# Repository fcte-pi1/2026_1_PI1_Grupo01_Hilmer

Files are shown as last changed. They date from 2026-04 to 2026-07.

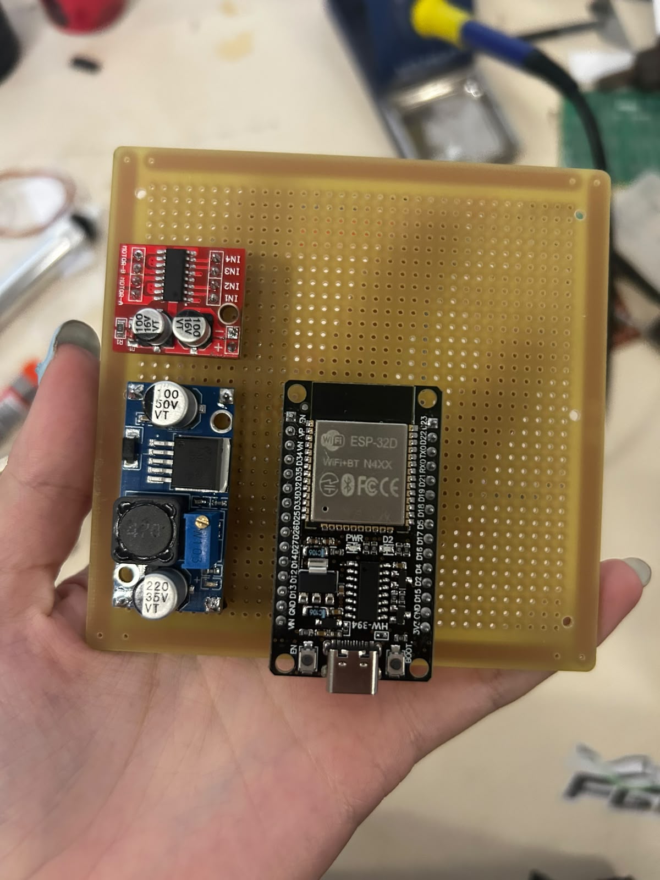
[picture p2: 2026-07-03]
hw/img/4.jpeg

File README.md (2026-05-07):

# Template PI1

Esse é o _template_ de repositório para ser utilizado pelos grupos de PI1 para organizar seu projeto. O _template_ é dividido em pastas, onde cada parte do projeto deve ser armazenada. Os arquivos a serem armazenados incluem documentação, código-fonte, arquivos de CAD, esquemáticos, arquivos de simulação de circuitos, e dados.

A organização e a correta utilização do repositório do projeto serão considerados na avaliação do grupo. Dessa forma, recomenda-se que *todos os membros* do grupo leiam as instruções deste repositório, aprendam a a utilizar o git (caso ainda não saibam) e também que o grupo combine uma estratégia de como irão utilizar o repositório em conjunto. Dessa forma não deixem de utilizar todas as ferramentas que o GitHub oferece, incluindo branchs, PRs, revisões, issues, calendários, dentre outros.

Lembrem sempre de evitar enviar arquivos muito grandes (>5MB). No caso de vídeos e outros arquivos pesados que são necessários, armazenar o arquivo em outra plataforma e colocar aqui apenas o _link_.

> [!IMPORTANT]
> A estrutura de pastas do projeto não reflete a divisão de equipes. Os membros podem e devem trabalhar nas diferentes pastas a depender da necessidade do projeto.

## Utilização

1. Crie o repositório do projeto utilizando a nomenclatura padrão no formato: `<ano>.<semestre>_PI1_Grupo<n>_<professor>`. Como um exemplo, um nome formado corretamente seria `2026.1_PI1_Grupo1_Diogo`. 

2. Crie uma equipe do projeto com a mesma nomenclatura do repositório porém com o sufixo `_Equipe`, como `2026.1_PI1_Grupo1_Diogo_Equipe`, e solicite, caso necessário, que a equipe tenha permissão de escrita no repositório do projeto.

## Configuração de ambiente

O script [scripts/setup_dev_env.sh](/home/lucasmf/projects/PI1/2026_1_PI1_Grupo01_Hilmer/scripts/setup_dev_env.sh:1) prepara o ambiente de desenvolvimento levando em conta o estado atual do projeto:

- frontend em `React + Vite`
- backend em `Node.js`
- banco de dados ainda pendente de definição
- comunicação com sensores por `HTTP`, com hardware ainda pendente de definição
- auditoria da estrutura atual do repositório ao final da execução

Para instalar dependências e validar o ambiente:

```bash
bash scripts/setup_dev_env.sh install
```

Esse modo instala apenas as dependências do projeto, com base nos `package.json` de `src/backend` e `src/frontend`.

Para instalar pacotes de sistema necessários ao ambiente:

```bash
bash scripts/setup_dev_env.sh install-system
```

Para apenas checar o ambiente atual, sem instalar nada:

```bash
bash scripts/setup_dev_env.sh check
```

Para iniciar frontend e backend automaticamente:

```bash
bash scripts/start_dev.sh
```

Esse script sobe os dois serviços juntos e encerra ambos ao usar `Ctrl+C`.

O script tenta instalar:

- dependências de `src/backend` quando existir `package.json`
- dependências de `src/frontend` quando existir `package.json`

No modo `install-system`, o script tenta instalar:

- `git`
- `curl`
- utilitários básicos de compilação do sistema

Observações:

- O modo `install` não usa `sudo` nem instala pacotes do sistema.
- Em Linux/macOS, o modo `install-system` pode pedir `sudo`.
- O script usa `npm ci` quando existir `package-lock.json`; caso contrário, usa `npm install`.
- O script copia `.env.example` para `.env` em `src/backend` e `src/frontend` quando esses arquivos existirem.
- O banco de dados e o hardware de comunicação com sensores ainda precisam ser definidos pelo time.

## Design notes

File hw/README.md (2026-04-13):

# _Hardware_

Esta pasta deverá armazenar arquivos referentes a:

- Simulações de circuitos eletrônicos (alimentação, sensores, atuadores etc.): [Qucs](https://qucs.sourceforge.net/), [QSPICE](https://www.qorvo.com/design-hub/design-tools/interactive/qspice), [Fritzing](https://fritzing.org/), dentre outros.
- Esquemáticos de circuitos: [KiCad](https://www.kicad.org/), Qucs, QSPICE.
- Diagramas de bloco: [Canva](https://www.canva.com/pt_br/), [TikZ](https://tikz.net/).
- _Datasheets_ de componentes eletrônicos, microcontroladores, _shields_ Arduino, motores etc.
- Testes tabelados de circuitos: arquivos CSV, Excel.
- Imagens PNG e JPEG de resultados práticos: fotos de testes reais, gráficos de resultados etc.
- Outros arquivos referentes ao _hardware_ do projeto.

> [!WARNING]
> **Não acrescente código-fonte a esta pasta.** O código desenvolvido para microcontroladores e SOCs ([Arduino](https://www.arduino.cc/), [ESP32](https://www.espressif.com/), [Raspberry Pi](https://www.raspberrypi.com/)) deverá ser armazenado na pasta [src/firmware](https://github.com/fcte-pi1/template/tree/main/src/firmware) deste repositório.

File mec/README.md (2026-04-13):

# _Mecânica e Estruturas_

Esta pasta deverá ser utilizada para armazenar arquivos relativos ao projeto estrutural, mecanismos, materiais, estudos aerodinâmicos, equações dinâmicas, construção e manufatura, impressão 3D, e correlatos.

Os arquivos a serem incluídos, são, dentre outros:
- Arquivos CAD de peças e montagens (FCStd, STEP, etc). 
- Desenhos técnicos (pdf, etc).
- Arquivos de impressão 3D (STL, etc).
- Imagens rasterizadas e vetorizadas (eps, pdf, svg, etc).
- Documentos e estudos realizados para o projeto (markdown, LaTeX, etc).

Durante o projeto, os grupos são encorajados a realizarem estudos para o projeto de estruturas, mecanismos, aerodinamica, dentre outros, e muitos desses estudos não caberão no relatório a ser entregue. Esses estudos podem ser colocados também nessa pasta, preferencialmente utilizando markdown (.md) para facilitar a leitura em ambiente web. Lembre-se que você pode utilizar equações em formato LaTeX no markdown e não deixe de utilizar links para o material de referencia que utilizaram. Estudos bem realizados contarão de maneira positiva na avaliação das equipes, porém lembre-se que não é permitida a utilização de IA, e que esse material deve ser principalmente útil à equipe.

> [!WARNING]
> Não acrecente arquivos da parte de hardware eletrônico aqui, como arquivos de KiCAD. Estes devem ser salvos na pasta [hw](https://github.com/fcte-pi1/template/tree/main/hw) deste repositório.

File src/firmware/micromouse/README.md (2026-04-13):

# _Firmware_
Esta pasta deverá armazenar arquivos referentes a:

- Código-fonte para microcontroladores e SOCs: [Arduino](https://www.arduino.cc/), [ESP32](https://www.espressif.com/), [Raspberry Pi](https://www.raspberrypi.com/), dentre outros.
- Projetos de organização destes códigos, caso utilize IDEs: [Arduino IDE](https://www.arduino.cc/en/software/), [Visual Studio](https://visualstudio.microsoft.com/pt-br/downloads/) etc.
- Arquivos de configuração: ```CMakeLists.txt``` se for usar [CMake](https://cmake.org/download/), ```Makefile``` se for usar [make](https://www.cs.colby.edu/maxwell/courses/tutorials/maketutor/) etc.

Evite incluir:
- Artefatos de compilação: os arquivos de saída compilados (binários, arquivos objeto, .hex, .elf) devem ser gerados pelo processo de compilação e não incluídos no repositório.
- Arquivos temporários/específicos do sistema operacional: Arquivos como .DS_Store (macOS) ou arquivos de configuração do editor (a menos que esteja usando uma configuração compartilhada como .editorconfig).
- Configurações pessoais: Arquivos de configuração locais específicos da máquina do desenvolvedor.

> [!WARNING]
> **Não acrescente arquivos referentes a _hardware_ nesta pasta.** Eles deverão ser armazenados na pasta [hw](https://github.com/fcte-pi1/template/tree/main/hw) deste repositório.

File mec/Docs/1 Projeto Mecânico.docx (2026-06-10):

1 Projeto Mecânico

  1.1 Análise Dinâmica

A primeira Lei de Newton define que a força resultante de um corpo é fruto do produto entre a massa e a aceleração. Portanto, é necessário analisar como a massa age no sistema de um micromouse e qual é o efeito da sua distribuição na estrutura, além de entender o funcionamento das forças que geram aceleração no rato. As análises realizadas aqui levam em conta a simplificação de que o centro de massa e o centro de gravidade (CG), local de atuação da força peso, coincidem quando o corpo é pequeno em relação à terra.

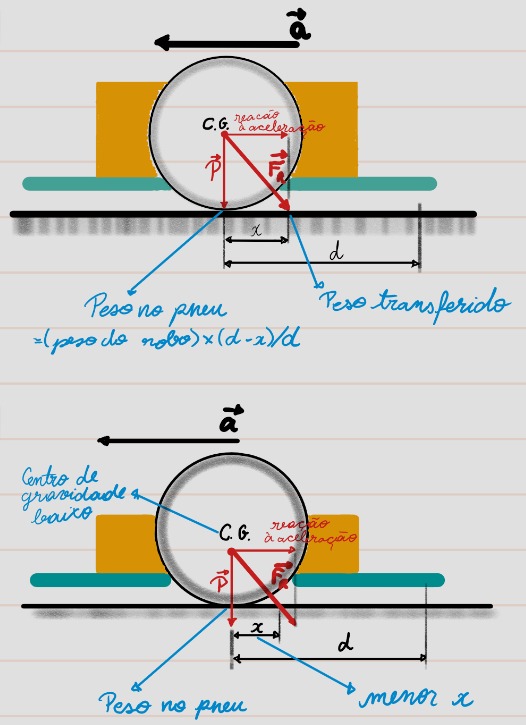
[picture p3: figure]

A força peso, e, portanto, a massa, possui três comportamentos importantes: no rato parado, no rato em aceleração ou desaceleração e no rato sob efeito de uma força centrípeta. Com o rato parado, todo o peso é transferido para as rodas, que são os pontos de contato do micromouse com o solo. Assim que o micromouse começa a acelerar, esse peso é deslocado por causa da reação à aceleração, como mostra a figura (nº da figura). Dessa forma, o peso para de manter a aderência do micromouse, pois ele se move para um ponto que não está em contato com o chão. O mesmo efeito ocorre na desaceleração, mas com sentido oposto.

Quando o CG é rebaixado, o vetor da força peso continua para além do solo, fazendo com que o deslocamento do peso diminua. Quanto mais baixo o CG, menor será o deslocamento do peso durante a aceleração, garantindo que ainda haja peso nas rodas e, portanto, que haja aderência. A fim de que o CG se mantenha próximo do solo e centralizado em relação aos pneus, os componentes mais pesados, como a bateria, são colocados no andar inferior do micromouse, perto das rodas, e de forma simétrica.

O momento em que o rato está sujeito à força centrípeta é quando ele realiza uma curva. Assim como no caso da aceleração, a força centrípeta gera uma reação que transfere o peso do centro do rato para a roda externa à curva. Essa transferência de peso para a extremidade gera um torque com centro de curvatura no ponto de contato entre a roda e o chão e raio do tamanho da distância do centro de gravidade ao solo. Dessa forma, quanto mais estreito o micromouse, mais o peso é transferido para a extremidade e quanto maior o CG, mais propenso o rato é a capotar na curva, pois exige menos esforço para gerar o torque. O diagrama de corpo livre da figura (nº da figura) demonstra que, para diminuir esse efeito, é preciso que o rato seja o mais largo possível e reitera a necessidade de um CG baixo.

  1.2 Dimensionamento

O estudo do comportamento das forças atuantes na movimentação do micromouse revelou duas coisas importantes para o dimensionamento: que as peças devem ser dispostas de modo a concentrar o peso na parte inferior e que o micromouse deve ser o mais largo possível. Contudo, ainda é preciso definir quais dimensões exatas são viáveis para o projeto.

A principal restrição de tamanho são as dimensões físicas do labirinto, pois o rato deve ser capaz, acima de tudo, de ser colocado dentro dele. Dessa forma, conclui-se que, no máximo, o micromouse pode ter 18cm de largura por 18 cm de comprimento. Apesar de ser um requisito importante, apenas caber no labirinto não garante que o micromouse será capaz de navegar por ele. Para isso, é preciso considerar a área que ele ocupa ao realizar as curvas, onde o espaço disponível para o rato é mínimo.

Existem diferentes curvaturas possíveis dentro do labirinto, contudo, mas mais críticas são as de 45º e de 90º, representadas na figura (nº da figura) são elas que delimitam, respectivamente, a maior largura e maior comprimento que o micromouse pode ter. Nas curvas de 45º o rato percorre um corredor decorrente de curvas consecutivas para lados alternados, o qual é limitado pelas quinas das paredes das células e possui uma largura de aproximadamente 127,3 mm. Sendo assim, a largura máxima que o micromouse pode ter é de 127 mm. Já nas curvas de 90º, o rato descreve uma trajetória com raio de 90mm, e a distância máxima entre o centro de rotação do rato e a sua extremidade é a que permite que esse trajeto seja realizado sem encostar nas paredes. Essa distância é de aproximadamente 101,1 mm, limitando o comprimento do micromouse a 202,2mm.

Para que o rato consiga realizar todo o caminho até a resposta sem obstáculos, optamos por deixar uma sobra de aproximadamente 60mm no comprimento e 30mm na largura, considerando que é importante o rato ser o mais largo possível. Assim, o rato possui 14cm de comprimento por 10cm de largura, sendo que o centro de rotação está situado no seu centro geométrico.

  1.3 Locomoção

A locomoção do micromouse depende, principalmente, do posicionamento e geometria das rodas e da disposição dos motores. Essas características são definidas por três propriedades: estabilidade, manobragem e controle (livrinho que eu vou mandar).

No âmbito da estabilidade, apenas duas rodas são necessárias, contudo, essa configuração requer rodas grandes demais para um micromouse. Sendo assim, o mínimo viável seria uma configuração de 2 rodas e outro ponto de apoio, ou 3 rodas (livrinho q eu vou mandar o nome). Como a bateria usada nesse projeto é pesada e compacta, é necessário aumentar a estabilidade adicionando mais uma roda. Dessa forma, o rato dispõe de um sistema de 4 rodas com tração dianteira.

Já sobre a manobragem, o micromouse precisa ser omnidirecional, ou seja, capaz de andar em qualquer direção ao longo do plano xy, definido pelo piso do labirinto. A configuração mais comum para esse tipo de robô é a de duas rodas com direção diferencial, ou seja, com um motor acoplado a cada roda para que elas se movam de forma independente. Esse micromouse utiliza 4 rodas para estabilidade adicional e um sistema de engrenagens que garante tração em todas as rodas, com diferencial entre a lateral esquerda e direita. Assim, as rodas rotacionam em torno do ponto central do rato (citaçãozinha).

Por fim, o controle possui uma conexão intrínseca com a manobragem, pois a disposição dos motores interfere diretamente em como as velocidades angular e linear são convertidas em sinais individuais para as rodas. O controle dos motores é realizado de forma independente por meio de um circuito de chaveamento baseado em flip-flop, permitindo o acionamento ou desligamento de cada motor conforme a necessidade de manobra. Essa estratégia possibilita um controle mais preciso do movimento do robô durante as mudanças de direção. Além disso, os drivers de motor são responsáveis por definir a velocidade de rotação, recebendo os sinais de comando do microcontrolador, que coordena todo o processo de acionamento. Dessa forma, o microcontrolador atua como a unidade central de controle, enquanto os drivers fazem a interface de potência necessária para o funcionamento dos motores, garantindo maior estabilidade, precisão e eficiência na execução das curvas.

  1.4 Design

Para comportar todos os componentes, o micromouse possui dois andares, com uma distância de 3cm entre si. Os andares foram impressos separadamente, tendo em vista que a impressora 3d funciona em camadas e entre os dois andares existe um espaço vazio onde precisariam ser colocados suportes. As colunas que conectam o chassis estão na mesma peça que o primeiro andar, com um arredondamento em suas bases para evitar a formação de um concentrador de tensão, o qual comprometeria a integridade física do chassis, pois as forças de compressão ficam concentradas na base da coluna. O mesmo processo de arredondamento foi aplicado para todos os ângulos do chassis, isso diminui o tempo de impressão e distribui a tensão nas intersecções.

O chassis foi impresso em PETG, um material conhecido por ter uma resistência térmica maior que o PLA e

  1.5 Simulações
  1.6 Testes físicos

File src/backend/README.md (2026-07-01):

# _Backend_

Esta pasta deverá armazenar arquivos referentes a:

- Código-fonte da API REST: rotas, controladores, modelos e lógica de negócio.
- Arquivos de configuração do servidor: `app.py`, `server.js`, `main.go` etc., dependendo da linguagem/framework utilizado ([Flask](https://flask.palletsprojects.com/), [FastAPI](https://fastapi.tiangolo.com/), [Express](https://expressjs.com/), [Django](https://www.djangoproject.com/) etc.).
- Arquivos de definição de dependências: `requirements.txt` ou `pyproject.toml` (Python), `package.json` (Node.js), `pom.xml` (Java/Maven) etc.
- Scripts de migração e esquemas de banco de dados: arquivos `.sql`, scripts de migração ([Alembic](https://alembic.sqlalchemy.org/), [Sequelize](https://sequelize.org/) etc.) e seeds de dados para desenvolvimento.
- Arquivos de configuração de ambiente: `.env.example` com as variáveis de ambiente necessárias (nunca o `.env` real).
- Arquivos de containerização: `Dockerfile` e `docker-compose.yml`, caso o serviço seja executado em contêiner.

Evite incluir:

- Credenciais e segredos: arquivos `.env`, chaves de API, senhas, tokens de acesso ou qualquer dado sensível **nunca** devem ser versionados.
- Artefatos de build: diretórios como `__pycache__/`, `dist/`, `build/`, `.eggs/` devem ser gerados localmente e ignorados via `.gitignore`.
- Dependências instaladas: pastas como `node_modules/` ou ambientes virtuais Python (`venv/`, `.env/`) não devem ser incluídos no repositório.
- Arquivos temporários/específicos do sistema operacional: arquivos gerados automaticamente pelo sistema ou pelo gerenciador de arquivos (ex.: `*~`, `.DS_Store`, `Thumbs.db`).
> [!WARNING]
> **Não acrescente arquivos referentes ao _frontend_ nesta pasta.** Eles deverão ser armazenados na pasta [frontend](https://github.com/fcte-pi1/template/tree/main/src/frontend) deste repositório.

---

# Rodando o Banco de Dados Localmente

## 📋 Pré-requisitos

| Ferramenta | Versão mínima | Download |
|---|---|---|
| Docker Desktop | 4.x | https://www.docker.com/products/docker-desktop |
| Node.js | 18.x | https://nodejs.org |
| npm | 9.x | Incluído com o Node.js |

> ⚠️ O Docker Desktop deve estar **aberto e rodando** antes de qualquer comando.

## Configuração para primeira vez

### 1. Clone o repositório e entre na pasta do backend

```bash
cd src/backend
```

### 2. Crie o arquivo `.env` a partir do exemplo

```bash
cp .env.example .env
```

Edite o `.env` com as credenciais do banco:
 
```env
DB_HOST=localhost
DB_PORT=5432
DB_NAME=micromouse_db
DB_USER=pi1_user
DB_PASSWORD=pi1senha123
```

### 3. Instale as dependências Node

```bash
npm install
```

---

## Subindo o banco

```bash
docker-compose up -d
```

Esse comando:
- Baixa a imagem `postgres:16` (apenas na primeira vez)
- Cria o container `micromouse_postgres`
- Executa o `schema.sql` automaticamente, criando todas as tabelas
- Persiste os dados no volume `pgdata`

Para verificar se está rodando:

```bash
docker ps
```

Você deve ver o container `micromouse_postgres` com status `Up`.

---

## Comandos úteis

| Ação | Comando |
|---|---|
| Subir o banco | `docker-compose up -d` |
| Parar o banco | `docker-compose stop` |
| Ver logs do banco | `docker-compose logs postgres` |
| Acessar o psql (terminal SQL) | `docker exec -it micromouse_postgres psql -U pi1_user -d micromouse_db` |

---

## Resetar o banco do zero

> Use isso quando precisar recriar as tabelas após mudanças no `schema.sql`.

```bash
docker-compose down -v
docker-compose up -d
```

O `-v` destrói o volume `pgdata`, forçando o PostgreSQL a re-executar o `schema.sql` na próxima subida.

---

## Rodando os testes

### Camadas (History / analise)

Na raiz do repositório (no Windows, **não** coloque comentários na mesma linha do comando):

```bash
npm run test:unit
npm run test:integration
npm run test:e2e
npm run test:all
```

| Comando | Precisa DB | Precisa servidor |
|---|---|---|
| `npm run test:unit` | Não | Não |
| `npm run test:integration` | Sim | Sim (`npm run dev` na porta 3001) |
| `npm run test:integration:all` | Sim | Sim (inclui WebSocket + server.test) |
| `npm run test:e2e` | Sim | Sim (reutiliza servidores locais se já estiverem rodando) |

Unitários cobrem `mouseService.analyzeAttempt`, rota `GET /historico/:id/analise` (mock), `History.jsx` e `analysisToMazeViewProps`. A fixture compartilhada fica em `tests/fixtures/analysisAttempt.js`.

### Testes de banco

Com o banco rodando, execute:

```bash
npm run test:db
```

Os testes verificam:

| # | O que testa |
|---|---|
| 1 | Conexão com o banco |
| 2 | Existência das tabelas (`historico`, `telemetria`, `trajeto`) |
| 3 | INSERT em `HISTORICO` |
| 4 | INSERT em `TELEMETRIA` com FK válida |
| 5 | INSERT em `TRAJETO` com múltiplos passos |
| 6 | Rejeição de FK inválida (integridade referencial) |
| 7 | Rejeição de direção inválida (CHECK constraint) |
| 8 | Rejeição de PK composta duplicada em `TRAJETO` |
| 9 | CASCADE DELETE (apagar HISTORICO remove filhos) |

Saída esperada ao passar em tudo:

```
=======================================================
  TESTES - Banco Micromouse PI1
=======================================================

📦 [1] Conexão com o banco
  ✅ PASSOU: Conexão estabelecida com sucesso

...

=======================================================
  Resultado: 9 passaram | 0 falharam
=======================================================
```

---

## ❓ Problemas comuns

**"Cannot connect to the Docker daemon"**
→ Abra o Docker Desktop e aguarde ele inicializar completamente.

**"password authentication failed"**
→ Confira se o `.env` está preenchido corretamente e se o banco foi criado com as mesmas credenciais.

**Tabelas não foram criadas**
→ O `schema.sql` só roda na primeira inicialização. Se o volume já existia, rode `docker-compose down -v` e suba novamente.

**Porta 5432 já em uso**
→ Outro PostgreSQL pode estar rodando na máquina. Altere `DB_PORT` no `.env` e no `docker-compose.yml` para outra porta (ex: `5433`).

---

# Guia de Integração — Micromouse PI1

Mapa do que foi alterado e como rodar tudo junto.

---

## O que mudou

| Arquivo | Situação anterior | Agora |
|---|---|---|
| `backend/src/server.js` | node:http puro + array em memória | Express + PostgreSQL real |
| `backend/src/services/mouseService.js` | Vazio | FloodFill BFS funcional |
| `backend/src/services/simulationService.js` | Não existia | CRUD no banco |
| `backend/src/routes/simulationRoutes.js` | Não existia | GET + POST /api/simulations |
| `backend/src/database/schema.sql` | Sem tabela simulations | Tabela `simulations` criada |
| `frontend/src/services/apiService.js` | Não existia | Todos os fetch centralizados |
| `frontend/src/hooks/useTelemetryData.js` | Só mock | Mock + WebSocket real (por variável de ambiente) |
| `frontend/src/pages/History.jsx` | Vazia/estática | Lê do banco via API |
| `frontend/src/pages/NewAttempt.jsx` | Sem integração | Salva simulação no banco |

---

## Como rodar

### 1. Banco de dados
```bash
# Na raiz do backend
cp .env.example .env       # editar se necessário
docker compose up -d       # sobe o PostgreSQL
```
O schema.sql é executado automaticamente pelo Docker na primeira vez.

### 2. Backend
```bash
cd backend
npm install
npm run dev    # ou: node src/server.js
```

### 3. Frontend
```bash
cd frontend
cp .env.example .env       # ajustar VITE_TELEMETRY_MODE=mock|live
npm install
npm run dev
```

---

## Variáveis de ambiente importantes

### Backend (`backend/.env`)
```
HOST=127.0.0.1
PORT=3001
FRONTEND_ORIGIN=http://localhost:5173
DB_HOST=localhost
DB_PORT=5432
DB_NAME=micromouse_db
DB_USER=pi1_user2
DB_PASSWORD=senhafalsa123
ESP32_WS_URL=ws://192.168.4.1:81   # IP da ESP32 na rede local
```

### Frontend (`frontend/.env`)
```
VITE_API_URL=http://localhost:3001
VITE_WS_URL=ws://localhost:3001
VITE_TELEMETRY_MODE=mock   # trocar para 'live' com hardware
```

---

## TODOs pendentes para integração completa

- [ ] **NewAttempt**: adicionar inputs para `mouseName` e `algorithmUsed`
- [ ] **Dashboard → NewAttempt**: implementar callback de conclusão para salvar simulação automaticamente ao terminar
- [ ] **mouseService**: integrar com `FloodFill.cpp` via WebAssembly ou child_process
- [ ] **ESP32**: validar schema do payload JSON recebido via WebSocket
- [ ] **simulationService**: adicionar paginação no `getAllSimulations()`
- [ ] **schema.sql**: adicionar tabelas `HISTORICO`, `TELEMETRIA`, `TRAJETO` do modelo SBD2
- [ ] **Autenticação**: adicionar middleware de API key ou JWT antes do deploy

---

## Fluxo de dados completo

```
ESP32-C3
   │ WebSocket (ws://192.168.4.1:81)
   ▼
backend/server.js
   │ retransmite via WebSocket
   ▼
frontend/useTelemetryData.js  (modo 'live')
   │ atualiza estado React
   ▼
Dashboard.jsx → MazeView.jsx

── HTTP REST ──────────────────────────────
NewAttempt.jsx
   │ POST /api/simulations
   ▼
simulationRoutes.js → simulationService.js → PostgreSQL

History.jsx
   │ GET /api/simulations
   ▼
simulationRoutes.js → simulationService.js → PostgreSQL
```

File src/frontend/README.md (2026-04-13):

# _Frontend_

Esta pasta deverá armazenar arquivos referentes a:

- Código-fonte da interface: componentes, páginas, estilos e lógica de apresentação, organizados conforme o framework utilizado ([React](https://react.dev/), [Vue](https://vuejs.org/), [Angular](https://angular.io/) etc.).
- Arquivos de marcação e estilo estáticos: `index.html`, arquivos `.css`, `.scss` ou `.sass` de estilização global.
- Arquivos de definição de dependências: `package.json` e `package-lock.json` (ou `yarn.lock`) com todas as bibliotecas utilizadas.
- Arquivos de configuração do bundler/toolchain: `vite.config.js`, `webpack.config.js`, `tsconfig.json` etc.
- Arquivos de configuração de ambiente: `.env.example` com as variáveis de ambiente públicas necessárias (ex.: URL base da API).
- Arquivos de containerização: `Dockerfile` e `docker-compose.yml`, caso a aplicação seja servida via contêiner.

Evite incluir:

- Dependências instaladas: a pasta `node_modules/` deve ser gerada localmente via `npm install` ou equivalente e nunca incluída no repositório.
- Artefatos de build: diretórios como `dist/`, `build/` ou `.next/` são gerados pelo processo de compilação e não devem ser versionados.
- Arquivos de configuração pessoal: arquivos como `.directory` (Linux/KDE) ou configurações locais de editor (ex.: `.vscode/settings.json`), salvo configurações compartilhadas como `.editorconfig`.
- Credenciais e segredos: arquivos `.env` com valores reais nunca devem ser versionados.

> [!WARNING]
> **Não acrescente arquivos referentes ao _backend_ nesta pasta.** Eles deverão ser armazenados na pasta [backend](https://github.com/fcte-pi1/template/tree/main/src/backend) deste repositório.

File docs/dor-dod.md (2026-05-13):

# Definição

A Definição de Preparado, ou Definition of Ready (DoR), estabelece critérios que indicam se um requisito está preparado para ser adicionado ao backlog da Sprint. Enquanto que a Definição de Pronto, ou Definition of Done (DoD), define os parâmetros para que aquela atividade da Sprint esteja pronta para ser apresentada na Sprint Review. 

## DoR
1. O requisito possui informação necessária para ser trabalhado?
 
2. O requisito cabe em uma sprint?
 
3. O requisito, caso correspondente ao software, está representado por uma história de usuário?

4. O requisito possui critérios de aceitação suficientes, referentes aos pacotes de trabalho necessários para cada área envolvida?

5. Se houver, as dependências do requisito estão identificadas?
    
## DoD
1. Entrega um incremento do produto?

2. Os critérios de aceitação estão contemplados?

3. Os testes de integração estão documentados?

4. Os arquivos adicionados ou alterados não desrepeitam a organização de nenhuma dessas pastas: docs, hw, mec, src(backend, firmware, frontend)?

5. Existe algum arquivo maior do que 5MB que está sendo enviado ao repositório?

### Considerações ao DoD

- Para o critério 4, verifique as instruções presentes no README.md da pasta em que está sendo trabalhada.
  
- Se o critério 5 for verdadeiro, armazene o arquivo em outra plataforma e coloque aqui apenas o link de direcionamento externo.

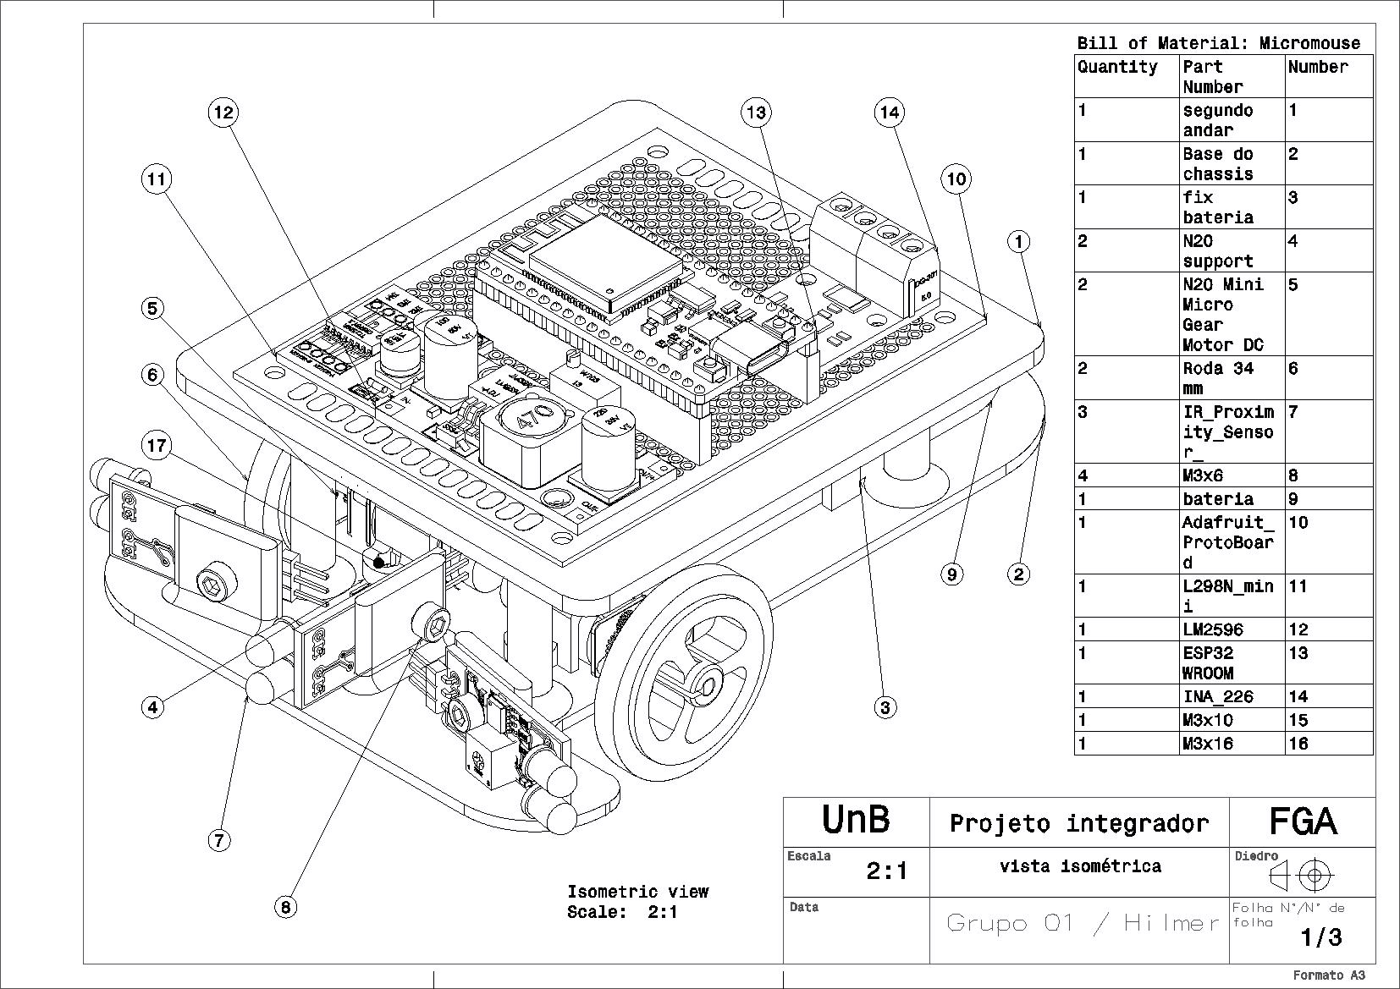
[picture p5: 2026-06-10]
mec/Docs/Micromouse.jpg

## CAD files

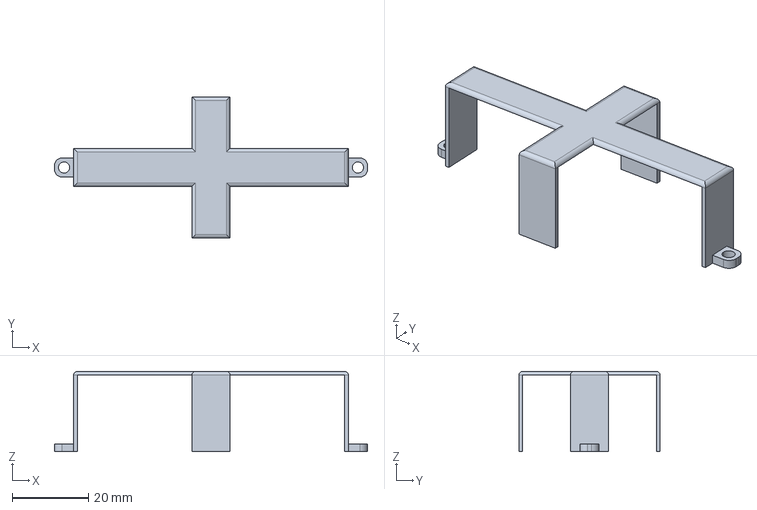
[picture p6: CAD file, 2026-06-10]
mec/Cads/Micromouse/arquivos para impressão/Bracket_Bateria.stp
82.0 x 37.0 x 21.0 mm

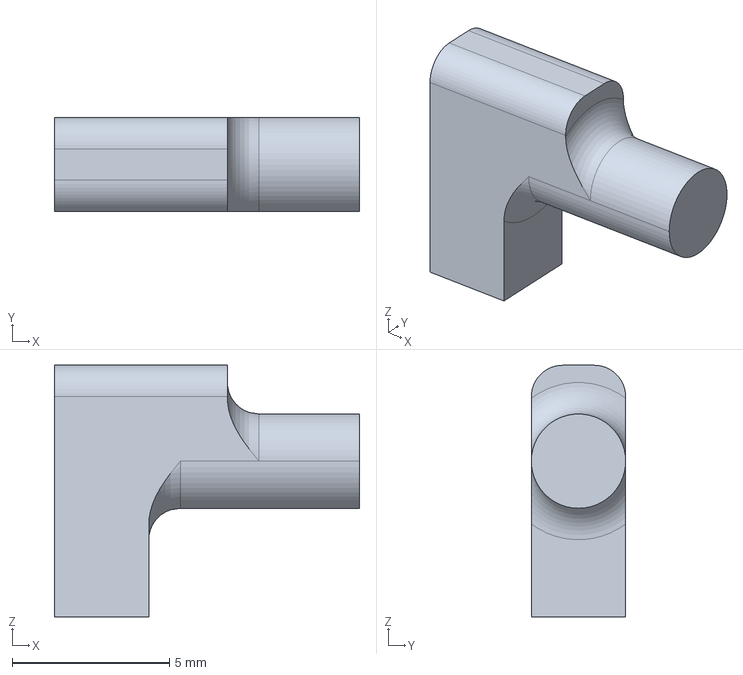
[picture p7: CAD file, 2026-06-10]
mec/Cads/Micromouse/arquivos para impressão/Apoio_Final.stp
9.70 x 3.00 x 8.00 mm

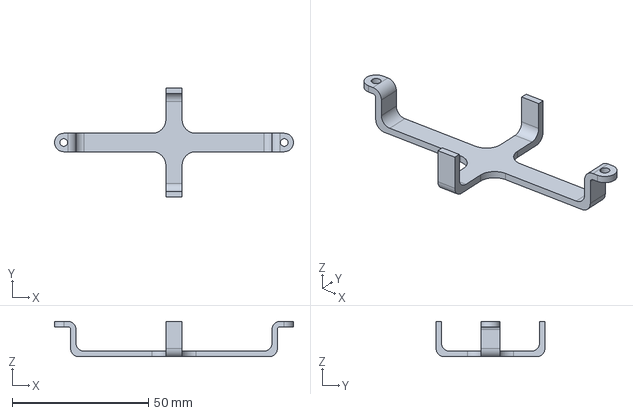
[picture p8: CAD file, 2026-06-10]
mec/Cads/Micromouse/arquivos para impressão/Fix_Bateria.stp
87.8 x 40.0 x 13.0 mm

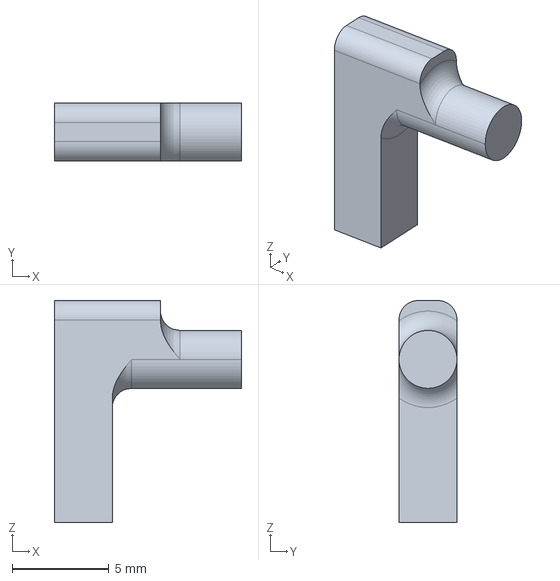
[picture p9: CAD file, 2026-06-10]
mec/Cads/Micromouse/arquivos para impressão/Apoio_Meio.stp
9.70 x 3.00 x 11.5 mm

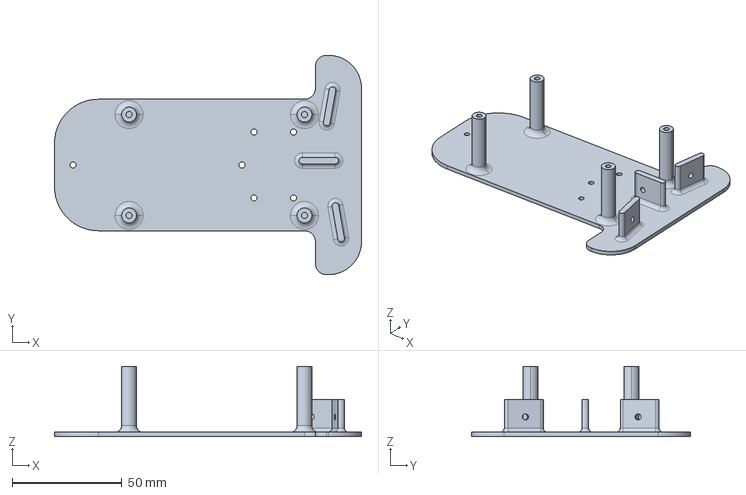
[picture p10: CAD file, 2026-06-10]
mec/Cads/Micromouse/arquivos para impressão/Base do chassis.stp
140.0 x 100.0 x 32.0 mm

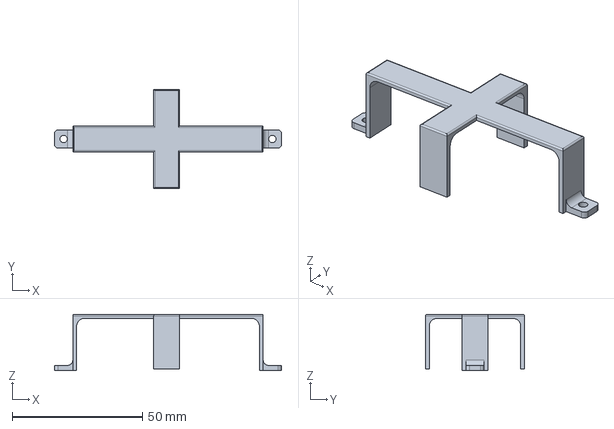
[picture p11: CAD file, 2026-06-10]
mec/Cads/Micromouse/arquivos para impressão/Bracket_Bateria_atualizado.stp
87.0 x 38.0 x 21.5 mm

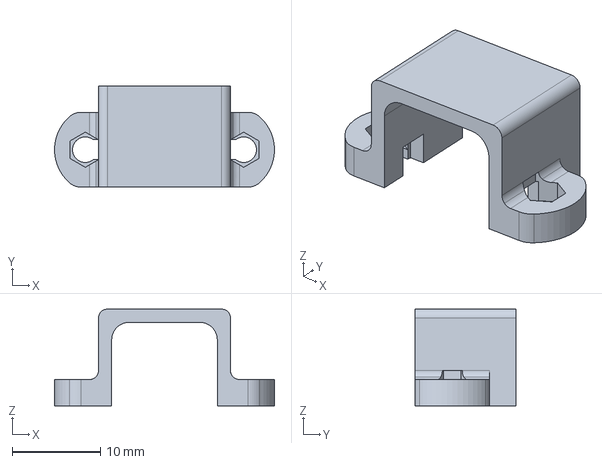
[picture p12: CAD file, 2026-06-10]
mec/Cads/Micromouse/arquivos para impressão/Bracket.stp
25.0 x 11.5 x 11.0 mm

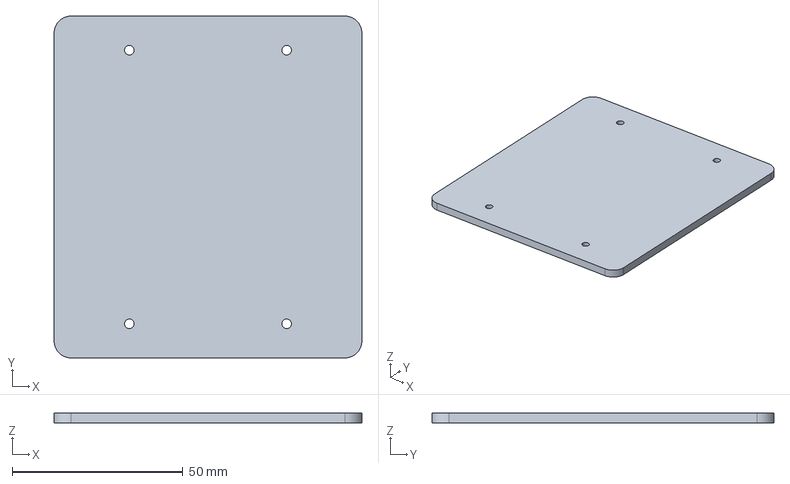
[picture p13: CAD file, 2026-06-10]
mec/Cads/Micromouse/arquivos para impressão/segundo andar.stp
90.0 x 100.0 x 3.00 mm

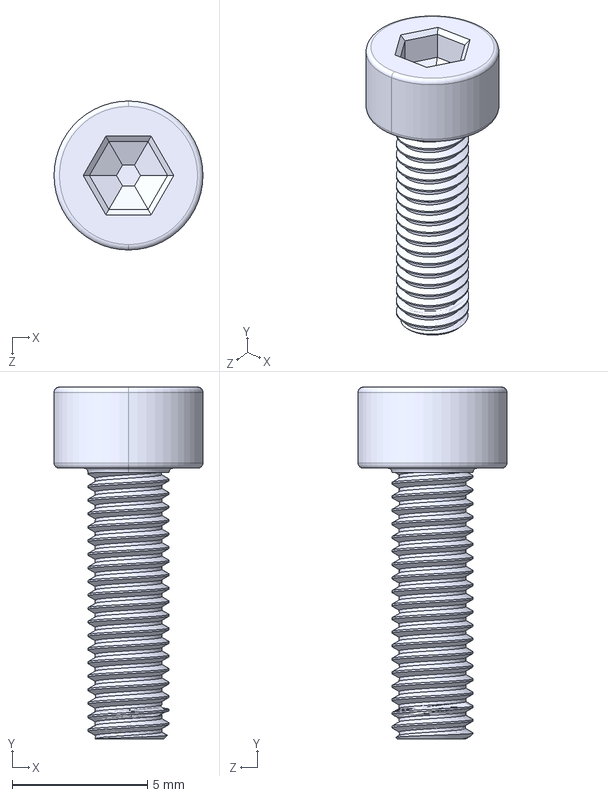
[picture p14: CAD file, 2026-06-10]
mec/Cads/Micromouse/parafusos/M3x10.STEP
5.50 x 13.0 x 5.50 mm

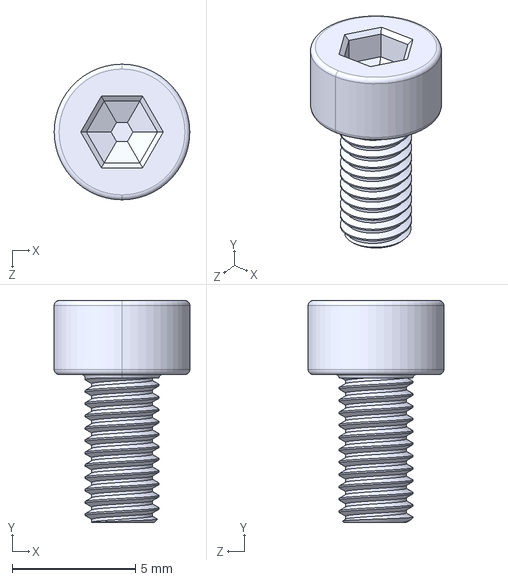
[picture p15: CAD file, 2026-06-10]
mec/Cads/Micromouse/parafusos/M3x6.STEP
5.50 x 9.00 x 5.50 mm

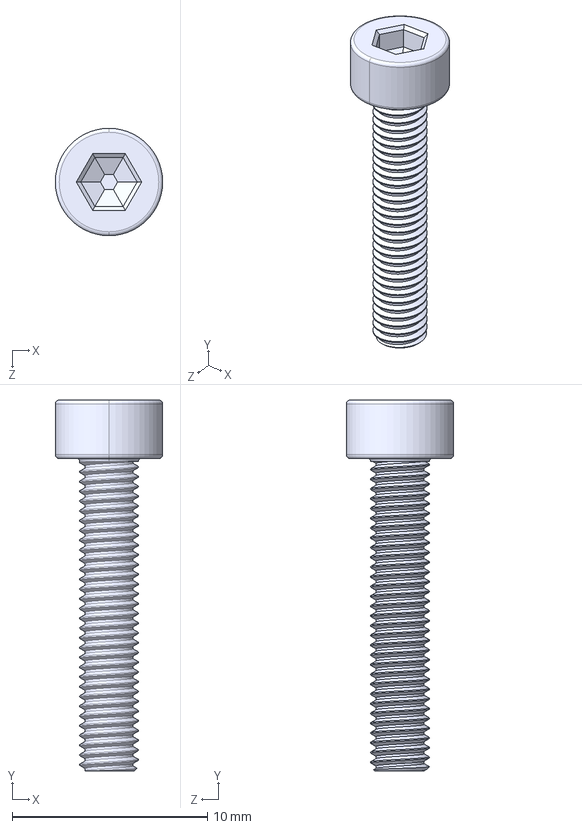
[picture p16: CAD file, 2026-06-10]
mec/Cads/Micromouse/parafusos/M3x16.STEP
5.50 x 19.0 x 5.50 mm

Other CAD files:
mec/Cads/Micromouse/arquivos para impressão/Base do chassis atualizada.stp
mec/Cads/Labirinto/Celula de labirinto.CATProduct
mec/Cads/Labirinto/Coluna.CATPart
mec/Cads/Labirinto/Labirinto 4x4.CATProduct
mec/Cads/Labirinto/Linha labirinto.CATProduct
mec/Cads/Labirinto/Parede.CATPart
mec/Cads/Labirinto/Piso.CATPart
mec/Cads/Micromouse/Apoio_Final.CATPart
mec/Cads/Micromouse/Apoio_Meio.CATPart
mec/Cads/Micromouse/Base do chassis.CATPart
mec/Cads/Micromouse/Bracket.CATPart
mec/Cads/Micromouse/Bracket_Bateria.CATPart
mec/Cads/Micromouse/Driver.CATPart
mec/Cads/Micromouse/Eixo_Atras.CATPart
mec/Cads/Micromouse/Engrenagem.CATPart
mec/Cads/Micromouse/Engrenagem_Eixo.CATPart
mec/Cads/Micromouse/Fix_Bateria.CATPart
mec/Cads/Micromouse/IR_Proximity_Sensor_.CATPart
mec/Cads/Micromouse/M3x10.CATPart
mec/Cads/Micromouse/M3x16.CATPart
mec/Cads/Micromouse/M3x6.CATPart
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

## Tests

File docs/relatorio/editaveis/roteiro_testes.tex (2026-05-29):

\item \textbf{ Roteiro de testes funcionais:}
\begin{itemize}
    \item Código do caso de teste: CT01
    \item Nome do caso de teste: Chegar ao Centro
    \item Objetivo do caso de teste: Verificar se o robô consegue calcular a rota correta do início (0,0) até o centro do labirinto usando o algoritmo FloodFill.
    \item Pré-condições do sistema para o teste ser realizado: O ambiente de simulação ou labirinto físico deve estar montado.
    \item Descrição dos procedimentos a serem executados para o teste: Executar a simulação e observar o comportamento e o caminho que o robô toma para chegar ao centro.
    \item Resultado esperado para o teste ser aprovado (pós-condição após realizado o teste): O robô atinge as coordenadas centrais e entra na fase 1.
\end{itemize}

\item \textbf{ Roteiro de testes funcionais:}
\begin{itemize}
    \item Código do caso de teste: CT02
    \item Nome do caso de teste: Explorar Retorno
    \item Objetivo do caso de teste: Verificar se o robô calcula a distância e navega corretamente de volta ao ponto (0,0).
    \item Pré-condições do sistema para o teste ser realizado: O robô deve estar no centro do labirinto (Fase 1 iniciada).
    \item Descrição dos procedimentos a serem executados para o teste: Analisar o caminho e a movimentação baseada nas leituras de parede (wallFront, wallLeft, wallRight).
    \item Resultado esperado para o teste ser aprovado (pós-condição após realizado o teste): O robô atinge as coordenadas (0,0) e passa à fase 2.
\end{itemize}

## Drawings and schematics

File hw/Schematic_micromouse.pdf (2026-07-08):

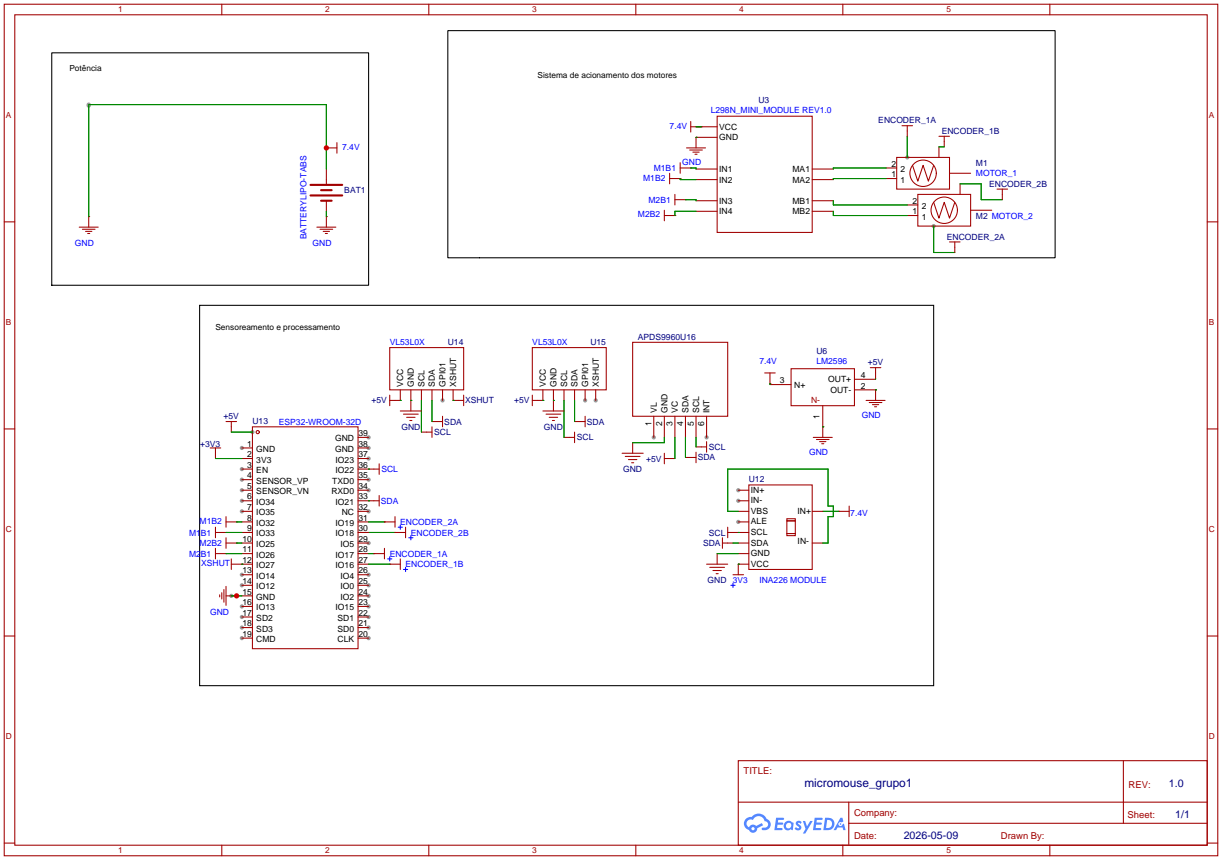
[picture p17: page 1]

Sistema de acionamento dos motores

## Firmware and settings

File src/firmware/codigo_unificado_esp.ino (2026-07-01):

// =============================================================================
// MICROMOUSE UNIFICADO — ESP32
// Flood Fill + Sensores filtrados + PWM separado por motor
// Versão ajustada:
// - Limpa filtro dos sensores após curvas
// - Não anda automaticamente depois de virar
// - Corrige giro de 180 graus
// - Aumenta PWM de frente para evitar andar fraco
// =============================================================================

#include <Arduino.h>
#include <ArduinoJson.h>
#include <WiFi.h>
#include <WebSocketsServer.h>
#include <stdint.h>

// =============================================================================
// PINOS
// =============================================================================
#define SENSOR_LEFT   34
#define SENSOR_FRONT  34
#define SENSOR_RIGHT  36

// Motores
// MOTOR_IN1 = motor esquerdo para trás
// MOTOR_IN2 = motor esquerdo para frente
// MOTOR_IN3 = motor direito para trás
// MOTOR_IN4 = motor direito para frente
#define MOTOR_IN1 25
#define MOTOR_IN2 26
#define MOTOR_IN3 32
#define MOTOR_IN4 33

// RGB desativado por enquanto
#define USE_RGB 0
#define SENSOR_RGB_PIN 0

// Botão não será usado para iniciar automaticamente
#define BUTTON_PIN 0

// =============================================================================
// CONFIGURAÇÕES
// =============================================================================
#define MAZE_SIZE    16
#define INF          255
#define FILTER_SIZE  5

// =============================================================================
// PWM DOS MOTORES
// =============================================================================
// Se puxar para a direita, reduza PWM_LEFT ou aumente PWM_RIGHT.
// Se puxar para a esquerda, aumente PWM_LEFT ou reduza PWM_RIGHT.
#define PWM_LEFT 88
#define PWM_RIGHT 75

// PWM usado nas curvas
#define TURN_PWM_LEFT 110
#define TURN_PWM_RIGHT 110

// Tempos de movimento
#define TURN_TIME_90        445
#define TURN_TIME_180       950
#define CELL_FORWARD_TIME   500
#define STOP_TIME           400

// Atualização dos sensores
#define SENSOR_UPDATE_TIME  20
#define PRINT_SENSOR_TIME   150

// Cor de chegada no sensor RGB
#define FINISH_COLOR  0xFFFFFF

// =============================================================================
// COMUNICAÇÃO WEB
// =============================================================================
const char *ssid = "Micromouse_Telemetry";
const char *password = "12345678";

WebSocketsServer webSocket = WebSocketsServer(81);
unsigned long lastTelemetryMillis = 0;

constexpr uint8_t MAP_SIZE = 33;
constexpr uint8_t PATH_CAPACITY = MAZE_SIZE * MAZE_SIZE;

// =============================================================================
// ENUMS
// =============================================================================
enum RobotState : uint8_t {
    DESLIGADO,
    AGUARDANDO_INICIO,
    MOVIMENTO_FRENTE,
    PARADO,
    GIRAR_DIREITA,
    GIRAR_ESQUERDA,
    GIRO_180,
    FINALIZADO
};

enum Direction : uint8_t {
    NORTH = 0,
    EAST  = 1,
    SOUTH = 2,
    WEST  = 3
};

enum MoveCommand : uint8_t {
    MOVE_FORWARD,
    TURN_LEFT_CMD,
    TURN_RIGHT_CMD,
    TURN_BACK_CMD,
    STOP_CMD
};

enum AbsoluteWall : uint8_t {
    WALL_NORTH = 0,
    WALL_EAST  = 1,
    WALL_SOUTH = 2,
    WALL_WEST  = 3
};

// =============================================================================
// STRUCTS
// =============================================================================
struct Cell {
    uint8_t dist;
    uint8_t visited   : 1;
    uint8_t northWall : 1;
    uint8_t southWall : 1;
    uint8_t eastWall  : 1;
    uint8_t westWall  : 1;
};

struct Position {
    int8_t r;
    int8_t c;
};

struct TelemetryPoint {
    int8_t row;
    int8_t col;
};

uint8_t mapaLabirinto[MAP_SIZE][MAP_SIZE];
TelemetryPoint caminhoPercorrido[PATH_CAPACITY];
uint16_t caminhoPercorridoSize = 0;
uint32_t numeroTentativa = 0;
unsigned long inicioCorrida = 0;
bool desafioCumprido = false;
String tempoConclusaoISO;

const int8_t deltaLinha[4] = {1, 0, -1, 0};
const int8_t deltaColuna[4] = {0, 1, 0, -1};
const char *nomesDirecao[4] = {"NORTE", "LESTE", "SUL", "OESTE"};

// =============================================================================
// SENSOR DE PAREDE COM FILTRO
// =============================================================================
struct SensorParede {
    int  pin;
    int  readings[FILTER_SIZE];
    int  index;
    bool wallDetected;
};

void initSensorParede(SensorParede &s) {
    s.index = 0;
    s.wallDetected = false;

    for (int i = 0; i < FILTER_SIZE; i++) {
        s.readings[i] = HIGH;
    }

    // GPIO 34, 35 e 36 são somente entrada.
    // Use INPUT, não INPUT_PULLUP.
    pinMode(s.pin, INPUT);
}

// LOW = parede
bool lerSensorFiltrado(SensorParede &s) {
    s.readings[s.index] = digitalRead(s.pin);
    s.index = (s.index + 1) % FILTER_SIZE;

    int leiturasLow = 0;

    for (int i = 0; i < FILTER_SIZE; i++) {
        if (s.readings[i] == LOW) {
            leiturasLow++;
        }
    }

    // Com 5 leituras, 3 LOW já contam como parede
    return leiturasLow >= 3;
}

bool dentroDoLabirinto(int8_t linha, int8_t coluna) {
    return linha >= 0 && linha < MAZE_SIZE && coluna >= 0 && coluna < MAZE_SIZE;
}

void inicializarMapaWeb() {
    for (uint8_t i = 0; i < MAP_SIZE; i++) {
        for (uint8_t j = 0; j < MAP_SIZE; j++) {
            if (i == 0 || i == MAP_SIZE - 1 || j == 0 || j == MAP_SIZE - 1) {
                mapaLabirinto[i][j] = 1;
            } else {
                mapaLabirinto[i][j] = 2;
            }
        }
    }
}

void celulaParaMapa(int8_t linha, int8_t coluna, uint8_t &mapaLinha, uint8_t &mapaColuna) {
    mapaLinha = (uint8_t)(linha * 2 + 1);
    mapaColuna = (uint8_t)(coluna * 2 + 1);
}

void marcarCelulaVisitada(int8_t linha, int8_t coluna) {
    if (!dentroDoLabirinto(linha, coluna)) {
        return;
    }

    uint8_t mapaLinha = 0;
    uint8_t mapaColuna = 0;
    celulaParaMapa(linha, coluna, mapaLinha, mapaColuna);
    mapaLabirinto[mapaLinha][mapaColuna] = 0;
}

void marcarSegmentoVisitado(int8_t linhaAnterior, int8_t colunaAnterior, int8_t linhaAtualWeb, int8_t colunaAtualWeb) {
    if (!dentroDoLabirinto(linhaAnterior, colunaAnterior) || !dentroDoLabirinto(linhaAtualWeb, colunaAtualWeb)) {
        return;
    }

    uint8_t linhaA = 0;
    uint8_t colunaA = 0;
    uint8_t linhaB = 0;
    uint8_t colunaB = 0;

    celulaParaMapa(linhaAnterior, colunaAnterior, linhaA, colunaA);
    celulaParaMapa(linhaAtualWeb, colunaAtualWeb, linhaB, colunaB);

    mapaLabirinto[(linhaA + linhaB) / 2][(colunaA + colunaB) / 2] = 0;
}

void registrarCaminho(int8_t linha, int8_t coluna) {
    if (caminhoPercorridoSize >= PATH_CAPACITY) {
        return;
    }

    caminhoPercorrido[caminhoPercorridoSize++] = {linha, coluna};
}

String timestampISO(unsigned long elapsedMillis) {
    unsigned long totalSeconds = elapsedMillis / 1000UL;
    unsigned int seconds = totalSeconds % 60UL;
    unsigned int minutes = (totalSeconds / 60UL) % 60UL;
    unsigned int hours = (totalSeconds / 3600UL) % 24UL;

    char buffer[25];
    snprintf(buffer, sizeof(buffer), "2026-06-27T%02u:%02u:%02uZ", hours, minutes, seconds);
    return String(buffer);
}

String direcaoParaTexto(uint8_t direcao) {
    if (direcao < 4) {
        return String(nomesDirecao[direcao]);
    }

    return String("NORTE");
}

bool atCenter(Position pos) {
    const int8_t mid = MAZE_SIZE / 2;
    return (pos.r == mid - 1 || pos.r == mid) && (pos.c == mid - 1 || pos.c == mid);
}

uint8_t posicaoParaDirecaoAtual(Direction dir) {
    switch (dir) {
        case NORTH: return 0;
        case EAST:  return 1;
        case SOUTH: return 2;
        case WEST:  return 3;
    }

    return 0;
}

void atualizarMapaMovimento(Position anterior, Position atual) {
    if (dentroDoLabirinto(anterior.r, anterior.c)) {
        marcarCelulaVisitada(anterior.r, anterior.c);
    }

    if (dentroDoLabirinto(atual.r, atual.c)) {
        marcarCelulaVisitada(atual.r, atual.c);
        marcarSegmentoVisitado(anterior.r, anterior.c, atual.r, atual.c);
        registrarCaminho(atual.r, atual.c);
    }
}

void preencherMatriz(JsonDocument &doc, const char *chave) {
    JsonArray matriz = doc[chave].to<JsonArray>();

    for (uint8_t i = 0; i < MAP_SIZE; i++) {
        JsonArray linha = matriz.add<JsonArray>();
        for (uint8_t j = 0; j < MAP_SIZE; j++) {
            linha.add(mapaLabirinto[i][j]);
        }
    }
}

void preencherPayloadWeb(JsonDocument &doc) {
    uint8_t posMapaLinha = 0;
    uint8_t posMapaColuna = 0;
    uint8_t startMapaLinha = 0;
    uint8_t startMapaColuna = 0;
    uint8_t goalMapaLinha = 0;
    uint8_t goalMapaColuna = 0;

    celulaParaMapa(currentPos.r, currentPos.c, posMapaLinha, posMapaColuna);
    celulaParaMapa(0, 0, startMapaLinha, startMapaColuna);
    celulaParaMapa((int8_t)(MAZE_SIZE / 2 - 1), (int8_t)(MAZE_SIZE / 2 - 1), goalMapaLinha, goalMapaColuna);

    doc["numTentativa"] = numeroTentativa;
    doc["tempoColeta"] = timestampISO(millis() - inicioCorrida);
    doc["tensaoRecente"] = 7.4;
    doc["correnteRecente"] = 1.0;
    doc["posHRecente"] = currentPos.c;
    doc["posVRecente"] = currentPos.r;
    doc["velocidadeAtual"] = 0.55;
    doc["bateriaAtual"] = 100.0;
    doc["tensaoAtual"] = 7.4;
    doc["sensorCor"] = "#000000";
    doc["sensorEsquerda"] = sensorEsq.wallDetected ? 1 : 0;
    doc["sensorDireita"] = sensorDir.wallDetected ? 1 : 0;
    doc["sensorFrontal"] = sensorFrente.wallDetected ? 1 : 0;
    doc["tipoLabirinto"] = "16x16";
    doc["desafioCumprido"] = desafioCumprido ? "SIM" : "NAO";
    doc["status"] = desafioCumprido ? "success" : "running";
    doc["elapsedSeconds"] = millis() / 1000.0;
    doc["batteryPercent"] = 100.0;
    doc["speedMps"] = 0.55;

    JsonArray position = doc["position"].to<JsonArray>();
    position.add(posMapaLinha);
    position.add(posMapaColuna);

    JsonArray start = doc["start"].to<JsonArray>();
    start.add(startMapaLinha);
    start.add(startMapaColuna);

    JsonArray goal = doc["goal"].to<JsonArray>();
    goal.add(goalMapaLinha);
    goal.add(goalMapaColuna);

    JsonArray path = doc["visitedPath"].to<JsonArray>();
    for (uint16_t i = 0; i < caminhoPercorridoSize; i++) {
        uint8_t mapaLinha = 0;
        uint8_t mapaColuna = 0;
        celulaParaMapa(caminhoPercorrido[i].row, caminhoPercorrido[i].col, mapaLinha, mapaColuna);

        JsonArray point = path.add<JsonArray>();
        point.add(mapaLinha);
        point.add(mapaColuna);
    }

    JsonObject trajetoriaAtual = doc["trajetoAtual"].to<JsonObject>();
    trajetoriaAtual["numTentativa"] = numeroTentativa;
    trajetoriaAtual["passo"] = caminhoPercorridoSize == 0 ? 1 : caminhoPercorridoSize;
    trajetoriaAtual["pos_h"] = currentPos.c;
    trajetoriaAtual["pos_v"] = currentPos.r;
    trajetoriaAtual["direcao"] = direcaoParaTexto(posicaoParaDirecaoAtual(currentDir));

    if (desafioCumprido) {
        doc["tempoConclusao"] = timestampISO(millis() - inicioCorrida);
    }

    preencherMatriz(doc, "mapa");

    JsonObject historico = doc["historico"].to<JsonObject>();
    historico["percentualBateria"] = 100.0;
    historico["velocidadeMedia"] = 0.55;
    historico["tempoConclusao"] = desafioCumprido ? timestampISO(millis() - inicioCorrida) : "";
    historico["desafioCumprido"] = desafioCumprido ? "SIM" : "NAO";
    historico["correnteEletrica"] = 1.0;
    historico["tensaoEletrica"] = 7.4;
    historico["tipoLabirinto"] = "16x16";
}

void webSocketEvent(uint8_t num, WStype_t type, uint8_t * payload, size_t length) {
    switch(type) {
        case WStype_DISCONNECTED:
            Serial.printf("[%d] Desconectado!\n", num);
            break;
        case WStype_CONNECTED: {
            IPAddress ip = webSocket.remoteIP(num);
            Serial.printf("[%d] Conectado de %d.%d.%d.%d\n", num, ip[0], ip[1], ip[2], ip[3]);
            break;
        }
        case WStype_TEXT:
            Serial.printf("[%d] Comando recebido: %s\n", num, payload);
            break;
        default:
            break;
    }
}

// Sensores globais
SensorParede sensorEsq    = {SENSOR_LEFT};
SensorParede sensorFrente = {SENSOR_FRONT};
SensorParede sensorDir    = {SENSOR_RIGHT};

void atualizarSensores() {
    sensorEsq.wallDetected    = lerSensorFiltrado(sensorEsq);
    sensorFrente.wallDetected = lerSensorFiltrado(sensorFrente);
    sensorDir.wallDetected    = lerSensorFiltrado(sensorDir);
}

// Limpa um sensor individual
void limparFiltroSensor(SensorParede &s) {
    s.index = 0;
    s.wallDetected = false;

    for (int i = 0; i < FILTER_SIZE; i++) {
        s.readings[i] = HIGH;
    }
}

// Limpa todos os filtros e força novas leituras
void limparFiltrosSensores() {
    limparFiltroSensor(sensorEsq);
    limparFiltroSensor(sensorFrente);
    limparFiltroSensor(sensorDir);

    for (int i = 0; i < FILTER_SIZE; i++) {
        atualizarSensores();
        delay(SENSOR_UPDATE_TIME);
    }
}

// =============================================================================
// SENSOR RGB
// =============================================================================
uint32_t lerRGB() {
#if USE_RGB
    // TODO: implementar leitura real do sensor RGB
    return 0x000000;
#else
    return 0x000000;
#endif
}

// =============================================================================
// FILA ESTÁTICA PARA FLOOD FILL
// =============================================================================
class PositionQueue {
private:
    Position data[MAZE_SIZE * MAZE_SIZE];
    uint16_t head = 0;
    uint16_t tail = 0;

public:
    void clear() {
        head = 0;
        tail = 0;
    }

    bool empty() const {
        return head == tail;
    }

    void push(Position p) {
        if (tail < MAZE_SIZE * MAZE_SIZE) {
            data[tail++] = p;
        }
    }

    Position pop() {
        return data[head++];
    }
};

// =============================================================================
// MAPA DO LABIRINTO
// =============================================================================
class MazeMap {
private:
    Cell cells[MAZE_SIZE][MAZE_SIZE];

public:
    void begin() {
        for (uint8_t r = 0; r < MAZE_SIZE; r++) {
            for (uint8_t c = 0; c < MAZE_SIZE; c++) {
                cells[r][c] = {INF, 0, 0, 0, 0, 0};
            }
        }

        // Paredes externas
        for (uint8_t i = 0; i < MAZE_SIZE; i++) {
            cells[0][i].southWall = 1;
            cells[MAZE_SIZE - 1][i].northWall = 1;
            cells[i][0].westWall = 1;
            cells[i][MAZE_SIZE - 1].eastWall = 1;
        }
    }

    inline Cell& get(int8_t r, int8_t c) {
        return cells[r][c];
    }

    inline bool valid(int8_t r, int8_t c) const {
        return r >= 0 && r < MAZE_SIZE && c >= 0 && c < MAZE_SIZE;
    }

    void setWall(Position pos, AbsoluteWall dir, bool wall) {
        if (!valid(pos.r, pos.c)) {
            return;
        }

        Cell &cur = get(pos.r, pos.c);

        switch (dir) {
            case WALL_NORTH:
                cur.northWall = wall;
                if (valid(pos.r + 1, pos.c)) {
                    get(pos.r + 1, pos.c).southWall = wall;
                }
                break;

            case WALL_SOUTH:
                cur.southWall = wall;
                if (valid(pos.r - 1, pos.c)) {
                    get(pos.r - 1, pos.c).northWall = wall;
                }
                break;

            case WALL_EAST:
                cur.eastWall = wall;
                if (valid(pos.r, pos.c + 1)) {
                    get(pos.r, pos.c + 1).westWall = wall;
                }
                break;

            case WALL_WEST:
                cur.westWall = wall;
                if (valid(pos.r, pos.c - 1)) {
                    get(pos.r, pos.c - 1).eastWall = wall;
                }
                break;
        }
    }
};

// =============================================================================
// FLOOD FILL
// =============================================================================
class FloodFillNavigator {
private:
    MazeMap *maze;
    PositionQueue queue;

    void processNeighbor(int8_t nr, int8_t nc, bool wall, uint8_t base) {
        if (wall || !maze->valid(nr, nc)) {
            return;
        }

        Cell &nbr = maze->get(nr, nc);

        if (nbr.dist != INF) {
            return;
        }

        nbr.dist = base + 1;
        queue.push({nr, nc});
    }

public:
    FloodFillNavigator(MazeMap *m) : maze(m) {}

    void computeMulti(Position goals[], uint8_t count) {
        for (uint8_t r = 0; r < MAZE_SIZE; r++) {
            for (uint8_t c = 0; c < MAZE_SIZE; c++) {
                maze->get(r, c).dist = INF;
            }
        }

        queue.clear();

        for (uint8_t i = 0; i < count; i++) {
            if (!maze->valid(goals[i].r, goals[i].c)) {
                continue;
            }

            maze->get(goals[i].r, goals[i].c).dist = 0;
            queue.push(goals[i]);
        }

        while (!queue.empty()) {
            Position p = queue.pop();
            Cell &cur = maze->get(p.r, p.c);
            uint8_t base = cur.dist;

            processNeighbor(p.r + 1, p.c, cur.northWall, base);
            processNeighbor(p.r - 1, p.c, cur.southWall, base);
            processNeighbor(p.r, p.c + 1, cur.eastWall, base);
            processNeighbor(p.r, p.c - 1, cur.westWall, base);
        }
    }
};
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
void loop() {
    if (estadoAtual == FINALIZADO) {
        webSocket.loop();
        return;
    }

    webSocket.loop();
    atualizarSensores();
    imprimirStatus();

    uint32_t corRGB = lerRGB();

    updateWalls();
    floodFill.computeMulti(centroGoals, 4);

    if (atCenter() || corRGB == FINISH_COLOR) {
        desafioCumprido = true;
        tempoConclusaoISO = timestampISO(millis() - inicioCorrida);
        estadoAtual = FINALIZADO;
        motors.stop();
        Serial.println("[MICROMOUSE] DESTINO ALCANCADO! Encerrando...");
    }

    if (estadoAtual != FINALIZADO) {
        MoveCommand cmd = navigator.decide(currentPos, currentDir);

        // Segurança: se o Flood Fill mandar ir para frente, mas tem parede,
        // escolhe uma alternativa simples.
        if (cmd == MOVE_FORWARD && sensorFrente.wallDetected) {
            if (!sensorDir.wallDetected) {
                cmd = TURN_RIGHT_CMD;
            } else if (!sensorEsq.wallDetected) {
                cmd = TURN_LEFT_CMD;
            } else {
                cmd = TURN_BACK_CMD;
            }
        }

        Position posicaoAnterior = currentPos;
        bool avancou = motors.execute(cmd);

        updatePosition(cmd, avancou);

        if (avancou) {
            atualizarMapaMovimento(posicaoAnterior, currentPos);
        }

        if (maze.valid(currentPos.r, currentPos.c)) {
            maze.get(currentPos.r, currentPos.c).visited = 1;
        }
    }

    publicarTelemetria();
    delay(20);
}

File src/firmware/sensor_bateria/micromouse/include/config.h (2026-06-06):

#ifndef CONFIG_H
#define CONFIG_H

#define SDA_PIN 8
#define SCL_PIN 9

#define INA226_ADDRESS 0x40

/*
    Limites da bateria LiPo 2S
*/

#define LOW_BATTERY_VOLTAGE 7.0
#define VERY_LOW_BATTERY_VOLTAGE 6.6
#define CRITICAL_BATTERY_VOLTAGE 6.0

#endif

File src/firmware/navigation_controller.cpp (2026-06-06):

#include <Arduino.h>
#include <stdint.h>

//GPIO CONFIGURATION

// Sensores
#define FRONT_SENSOR_PIN 34
#define RIGHT_SENSOR_PIN 35
#define LEFT_SENSOR_PIN  32

// Motores
#define MOTOR_IN1 25
#define MOTOR_IN2 26
#define MOTOR_IN3 27
#define MOTOR_IN4 14

// CONFIGURAÇÕES


#define MAZE_SIZE 16

#define INF 255

#define TURN_TIME_90   220
#define TURN_TIME_180  450

// Limite de segurança do PWM para proteger o driver MX1508
// 178 equivale a ~70% de 255 (Simula 6V)
#define MAX_PWM 178 

//ENUMS

enum Direction : uint8_t {
    NORTH = 0,
    EAST  = 1,
    SOUTH = 2,
    WEST  = 3
};

enum MoveCommand : uint8_t {
    MOVE_FORWARD,
    TURN_LEFT,
    TURN_RIGHT,
    TURN_BACK,
    STOP
};

enum AbsoluteWallDirection : uint8_t {
    WALL_NORTH = 0,
    WALL_EAST  = 1,
    WALL_SOUTH = 2,
    WALL_WEST  = 3
};

// STRUCTS


struct Cell {

    uint8_t dist;

    uint8_t visited : 1;

    uint8_t northWall : 1;
    uint8_t southWall : 1;
    uint8_t eastWall  : 1;
    uint8_t westWall  : 1;
};

struct Position {

    int8_t r;
    int8_t c;
};


//FILA ESTÁTICA
class PositionQueue {

private:

    Position data[MAZE_SIZE * MAZE_SIZE];

    uint16_t head = 0;

    uint16_t tail = 0;

public:

    inline void clear() {

        head = 0;

        tail = 0;
    }

    inline bool empty() {

        return head == tail;
    }

    inline void push(Position p) {

        data[tail++] = p;
    }

    inline Position pop() {

        return data[head++];
    }
};


//SENSOR MANAGER
class SensorManager {

public:

    void begin() {

        pinMode(FRONT_SENSOR_PIN, INPUT);

        pinMode(RIGHT_SENSOR_PIN, INPUT);

        pinMode(LEFT_SENSOR_PIN, INPUT);
    }

    inline bool wallFront() {

        return digitalRead(FRONT_SENSOR_PIN);
    }

    inline bool wallRight() {

        return digitalRead(RIGHT_SENSOR_PIN);
    }

    inline bool wallLeft() {

        return digitalRead(LEFT_SENSOR_PIN);
    }
};

//MOTOR CONTROLLER (AJUSTADO COM PWM)

class MotorController {

public:

    void begin() {

        pinMode(MOTOR_IN1, OUTPUT);
        pinMode(MOTOR_IN2, OUTPUT);

        pinMode(MOTOR_IN3, OUTPUT);
        pinMode(MOTOR_IN4, OUTPUT);

        stop();
    }

    inline void stop() {

        digitalWrite(MOTOR_IN1, LOW);
        digitalWrite(MOTOR_IN2, LOW);

        digitalWrite(MOTOR_IN3, LOW);
        digitalWrite(MOTOR_IN4, LOW);
    }

    inline void forward() {

        analogWrite(MOTOR_IN1, MAX_PWM);
        digitalWrite(MOTOR_IN2, LOW);

        analogWrite(MOTOR_IN3, MAX_PWM);
        digitalWrite(MOTOR_IN4, LOW);
    }

    inline void backward() {

        digitalWrite(MOTOR_IN1, LOW);
        analogWrite(MOTOR_IN2, MAX_PWM);

        digitalWrite(MOTOR_IN3, LOW);
        analogWrite(MOTOR_IN4, MAX_PWM);
    }

    inline void turnLeft() {

        digitalWrite(MOTOR_IN1, LOW);
        analogWrite(MOTOR_IN2, MAX_PWM);

        analogWrite(MOTOR_IN3, MAX_PWM);
        digitalWrite(MOTOR_IN4, LOW);
    }

    inline void turnRight() {

        analogWrite(MOTOR_IN1, MAX_PWM);
        digitalWrite(MOTOR_IN2, LOW);

        digitalWrite(MOTOR_IN3, LOW);
        analogWrite(MOTOR_IN4, MAX_PWM);
    }

    void execute(MoveCommand cmd) {

        switch(cmd) {

            case MOVE_FORWARD:

                forward();

                break;

            case TURN_LEFT:

                turnLeft();

                delay(TURN_TIME_90);

                forward();

                break;

            case TURN_RIGHT:

                turnRight();

                delay(TURN_TIME_90);

                forward();

                break;

            case TURN_BACK:

                turnRight();

                delay(TURN_TIME_180);

                forward();

                break;

            case STOP:

                stop();

                break;
        }
    }
};

// MAPEAMENTO
class MazeMap {

private:

    Cell cells[MAZE_SIZE][MAZE_SIZE];

public:

    void begin() {

        for (uint8_t r = 0; r < MAZE_SIZE; r++) {

            for (uint8_t c = 0; c < MAZE_SIZE; c++) {

                cells[r][c].dist = INF;

                cells[r][c].visited = 0;

                cells[r][c].northWall = 0;
                cells[r][c].southWall = 0;
                cells[r][c].eastWall  = 0;
                cells[r][c].westWall  = 0;
            }
        }

        // paredes externas

        for (uint8_t i = 0; i < MAZE_SIZE; i++) {

            cells[0][i].southWall = 1;

            cells[MAZE_SIZE - 1][i].northWall = 1;

            cells[i][0].westWall = 1;

            cells[i][MAZE_SIZE - 1].eastWall = 1;
        }
    }

    inline Cell& get(uint8_t r, uint8_t c) {

        return cells[r][c];
    }

    inline bool valid(int8_t r, int8_t c) {

        return (
            r >= 0 &&
            r < MAZE_SIZE &&
            c >= 0 &&
            c < MAZE_SIZE
        );
    }
};

// FLOOD FILL
class FloodFillNavigator {

private:

    MazeMap* maze;

    PositionQueue queue;

public:

    FloodFillNavigator(MazeMap* m)
        : maze(m) {}

    void compute(Position goal) {

        for (uint8_t r = 0; r < MAZE_SIZE; r++) {

            for (uint8_t c = 0; c < MAZE_SIZE; c++) {

                maze->get(r, c).dist = INF;
            }
        }

        if (!maze->valid(goal.r, goal.c)) {
            return;
        }

        queue.clear();

        maze->get(goal.r, goal.c).dist = 0;

        queue.push(goal);

        while (!queue.empty()) {

            Position p = queue.pop();

            Cell &cur = maze->get(p.r, p.c);

            uint8_t base = cur.dist;

            processNeighbor(
                p.r + 1,
                p.c,
                cur.northWall,
                base
            );

            processNeighbor(
                p.r - 1,
                p.c,
                cur.southWall,
                base
            );

            processNeighbor(
                p.r,
                p.c + 1,
                cur.eastWall,
                base
            );

            processNeighbor(
                p.r,
                p.c - 1,
                cur.westWall,
                base
            );
        }
    }

private:

    inline void processNeighbor(
        int8_t nr,
        int8_t nc,
        bool wall,
        uint8_t base
    ) {

        if (wall) {
            return;
        }

        if (!maze->valid(nr, nc)) {
            return;
        }

        Cell &nbr = maze->get(nr, nc);

        if (nbr.dist != INF) {
            return;
        }

        nbr.dist = base + 1;

        queue.push({nr, nc});
    }
};

// NAVIGATION CONTROLLER 
class NavigationController {

private:

    MazeMap* maze;
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

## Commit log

2026-04-29 Template de HU
    Template para criação de Issues de História de Usuário
2026-05-13 Adicionar DoR e DoD (#133)
    * docs: adicionar dor e dod preliminar
    * docs: atualiza critérios de DoR e DoD para ajusta-los de maneira mais geral às areas envolvidas como um todo
    * docs: adiciona critérios DoD sobre a organização de pastas
    * docs: corrigir formatação textual do README.md
    ---------
2026-05-18 Diagrama de Blocos
2026-05-29 Feat/tests (#164)
    * feat: add dashboard e historico mocados
    * Adição de telas de inicio e re-organização das rotas
    * feat: update telemetry data handling and maze configurations
    * Tests
    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
2026-06-02 Atualização do diagrama de blocos
2026-06-06 Feat/sensor distancia (#200)
    * Adicionar implementação do sensor de distância com filtragem e detecção de parede
    * fix: adicionando outras paredes e removendo arquivo sem importacia
    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
2026-06-06 Sensor rgb (#202)
    * feat: inicializa sensorRGB
    * feat(firmware): integrar objeto de telemetria doc para sensor RGB
    * fix: ajustando pinos destinados
    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
    [main.cpp]
2026-06-06 Codigo do sensor da bateria (#201)
    * Primeira versão da estrutura do código do sensor da bateria
    Versão inicial da estrutura, incluindo testes unitários.
    Como não tenho o hardware em mãos, não foi possível desenvolver testes que validam devidamente o INA226 e Arduino. Os testes dessa versão priorizam apenas a lógica e sintaxe do algoritmo.
    Uma vez que eu tiver o hardware, serão finalizados os testes que acomodam o Arduino, INA226, etc.
    * Opção de alternar entre simulação e hardware real
    * Aviso da tensão crítica e carga baixa
    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
2026-06-06 Feat/issue172 navigation controller part2 (#203)
    * feat: add unified navigation contrller
    * fix: ajuste quanto ao acionamento dos motores (utilizando PMW)
    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
    [navigation_controller.cpp]
2026-06-06 feat: implementação inicial do frontend com rotas, páginas e serviços (#163)
    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
2026-06-06 otimizacao de logica do floodfill e reestruturacao para maior adequacao a esp32. (#183)
2026-06-06 feat(backend): implementa endpoints e arquitetura para micromouse (#181)
2026-06-06 Implementa comunicação websocket e teste (#169)
    * feat: comunicação via websocket com a placa ESP32
    * feat: simulador esp para testes
    * feat: atualiza .env.example com a rota do websocket do simulador
    * feat: código da esp para comunicação websocket
    * feat: atualiza json para refletir melhor os dados de telemetria atuais
    * feat: configura ambiente de testes
    * feat: testes unitários relacionados ao backend
    * feat: configura o ambiente de firmware para testes
    * feat: teste de integração
    * fix: atualizando IP da ESP
    ---------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
    [esp32.cpp]
2026-06-08 Banco de Dados - Implementação Lógica (#171)
    * feat: adiciona banco lógico com postgresql e dois testes
    * Db tests adjustments
    * adições de constraints
    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
2026-06-08 chore: aprimora alocação memória algoritmo FloodFill e pasta firmware (#204)
    * Versão inicial da estrutura do código
    * refactor(FloodFill): otimiza código a ser utilizado pelo ESP32
    * chore: aprimora alocação de memória do alg. FloodFill e complementa conteúdo da pasta firmware para torná-la compatível
    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
2026-06-10 Arquivos de mecânica e estruturas
    [Apoio_Final.CATPart, Apoio_Final.stp, Apoio_Meio.CATPart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]
2026-06-15 Feat/filtro (#205)
    * feat: adicionar filtro no histórico
    * test(filtro): adiciona scripts e suites de testes para filtro de histórico de tentativas registradas no software web
    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
2026-07-01 Feat/webintegracao (#208)
    * Integração bruta, com conexão das rotas e ajuste de serviços. Falta teste com o docker! Documentado no readme.md!
    * fix: corrige erros de integração
    * fix: ajustes testes antigos
    * test: adiciona testes de integração e unitários no backend
    * fix: arrumando salvando na rota...
    * fix: trocando local de onde e salvo
    * fix: remove numTentativa from requests and database schema for automatic ID generation
    * fix: front do historico estava quebrado
    * feat: implement trajectory tracking and history display enhancements
    * fix: arruamndo os scripts
    * feat(otimizaçao trajeto): adiciona algoritmo para enviar ao micromouse, dentre os dois trajetos de explor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
    [codigo_unificado_esp.ino, esp32.cpp]
2026-07-03 Datasheets para fácil acesso
2026-07-08 Esquemático atualizado - pós modificação nos sensores
2026-07-08 Atualizando o diagrama de blocos
2026-07-08 removendo arquivo antigo do diagrama de blocos
